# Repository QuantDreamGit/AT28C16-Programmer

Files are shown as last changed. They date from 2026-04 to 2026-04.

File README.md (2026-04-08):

# 🧠 8-bit EEPROM Programmer & Display Decoder

This project implements an EEPROM-based lookup table to convert an 8-bit value into decimal digits using a hardware-only decoding approach.

The EEPROM is programmed using an Arduino Nano Every and a shift-register-driven address bus.

## 📌 Overview

The system:

* Converts `0x00–0xFF` into decimal digits
* Supports both **unsigned** and **two’s complement signed** formats
* Uses EEPROM as a **hardware lookup table**
* Drives a segmented display via precomputed values

## ⚙️ Architecture

* **MCU**: Arduino Nano Every (20 MHz)
* **Shift Register**: 74HC164 (serial → parallel address)
* **EEPROM**: AT28Cxx family
* **Data bus**: 8-bit parallel
* **Control signals**: `WE`, `OE`, `CLR`

Addresses are shifted serially into the 74HC164, while data is written in parallel.

## 🧩 EEPROM Memory Map

### Unsigned (`0x00–0xFF`)

| Address | Content |
| --- | --- |
| `0x000–0x0FF` | Ones |
| `0x100–0x1FF` | Tens |
| `0x200–0x2FF` | Hundreds |
| `0x300–0x3FF` | Sign (`0x00`) |

### Signed (`-128 → 127`)

| Address | Content |
| --- | --- |
| `0x400–0x4FF` | Ones |
| `0x500–0x5FF` | Tens |
| `0x600–0x6FF` | Hundreds |
| `0x700–0x7FF` | Sign (`0x00` / `0x80`) |

* Digits use `abs(value)`
* Negative numbers use sign byte `0x80`

## 🔢 Segment Encoding

| Digit | Hex |
| ----- | --- |
| 0 | `0x7B` |
| 1 | `0x12` |
| 2 | `0xB9` |
| 3 | `0xB3` |
| 4 | `0xD2` |
| 5 | `0xE3` |
| 6 | `0xEB` |
| 7 | `0x32` |
| 8 | `0xFB` |
| 9 | `0xF2` |
| - | `0x80` |

## 🛠️ Programming Flow

For each byte:

1. Clear shift register
2. Shift 11-bit address (MSB → LSB)
3. Set data bus (`D0–D7`)
4. Pulse `WE` (write enable)
5. Wait for write cycle (~2 ms)

Readback uses the same address logic with `OE` enabled.

## ⚡ Timing Notes

* Arduino @ 20 MHz → ~50 ns per cycle
* `digitalWrite()` already satisfies all timing constraints
* EEPROM write cycle dominates (~1–2 ms)
* No latch in 74HC164 → register is cleared before each address load

## 🖼️ Assets

### Schematic

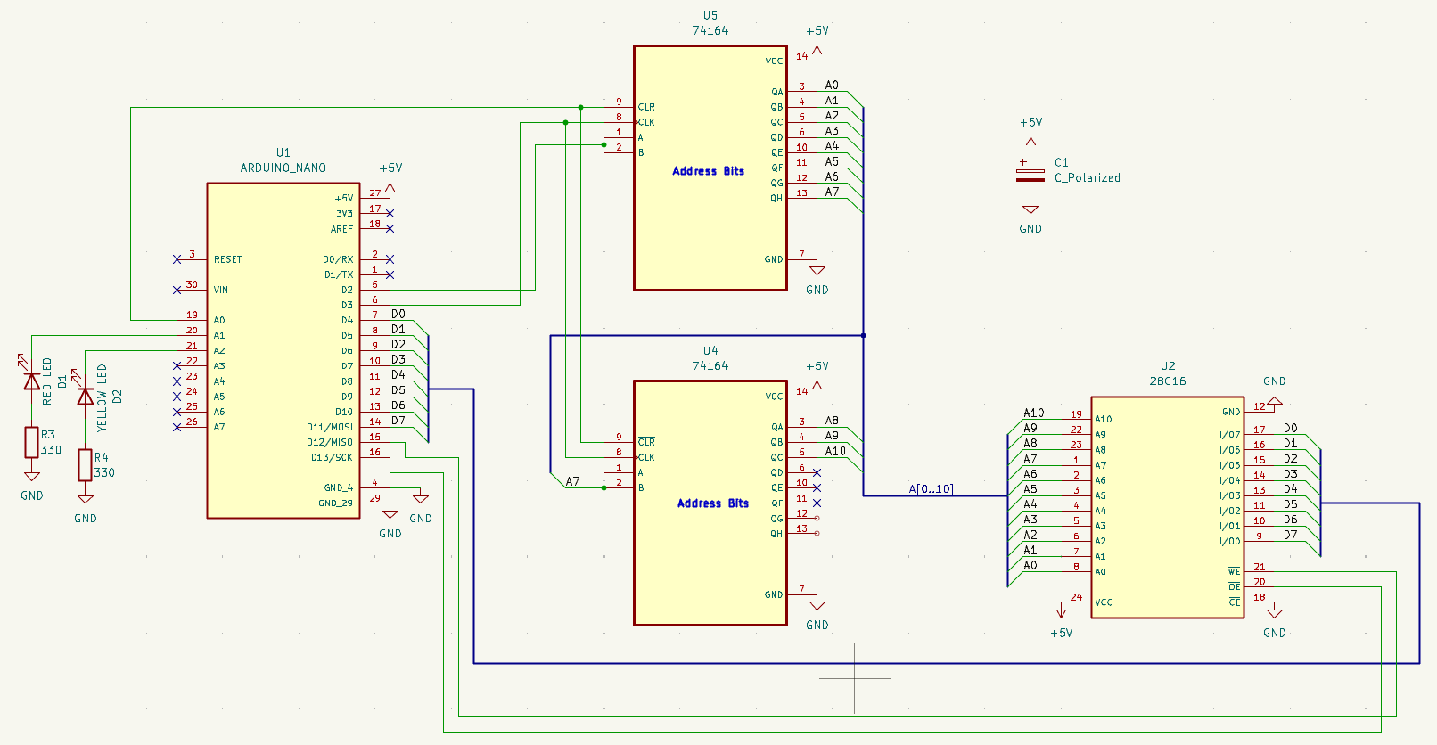
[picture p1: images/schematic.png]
Schematic


### PCB

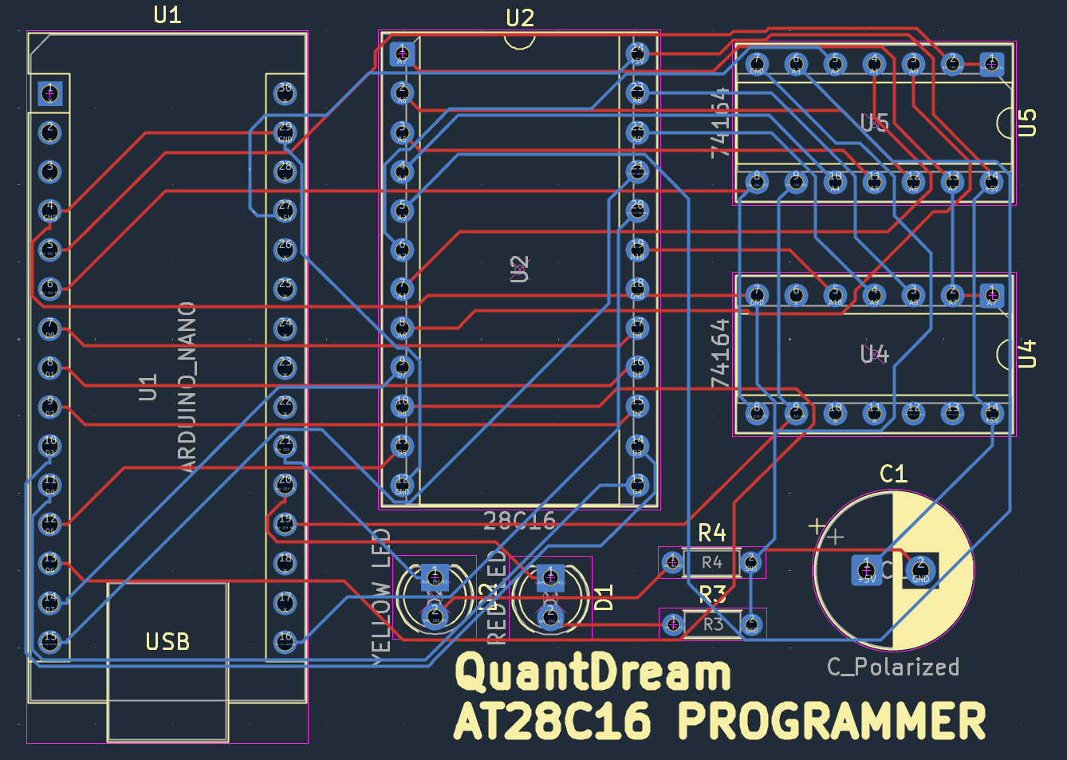
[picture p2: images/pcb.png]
PCB


### 3D View

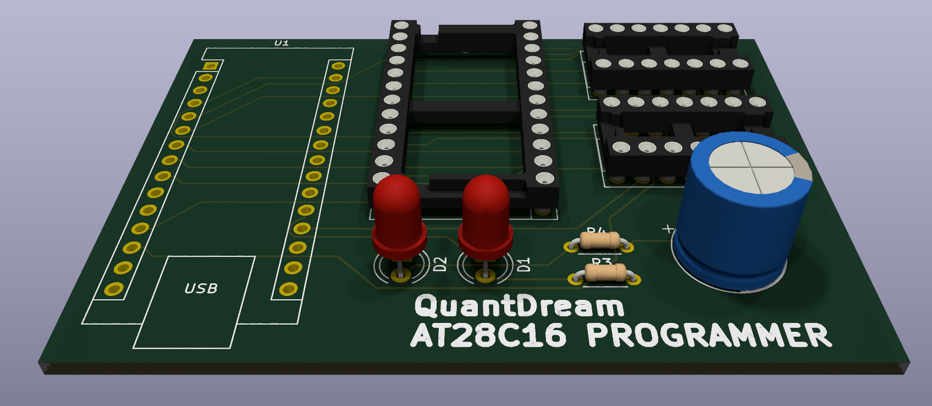
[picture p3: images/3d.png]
3D


### Gerbers

Gerbers

---

## 📁 Structure

```plaintext
.
├── firmware/
├── hardware/
├── images/
└── README.md
```

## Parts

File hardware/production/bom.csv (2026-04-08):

Designator | Footprint | Quantity | Value | LCSC Part #
C1 | CP_Radial_D10.0mm_P3.50mm | 1 | C_Polarized
D1 | LED_D4.0mm | 1 | RED LED
D2 | LED_D4.0mm | 1 | YELLOW LED
R3, R4 | R_Axial_DIN0204_L3.6mm_D1.6mm_P5.08mm_Horizontal | 2 | 330
U1 | Arduino_Nano | 1 | ARDUINO_NANO
U2 | DIP-24_W15.24mm_Socket | 1 | 28C16
U4, U5 | DIP-14_W7.62mm_Socket | 2 | 74164

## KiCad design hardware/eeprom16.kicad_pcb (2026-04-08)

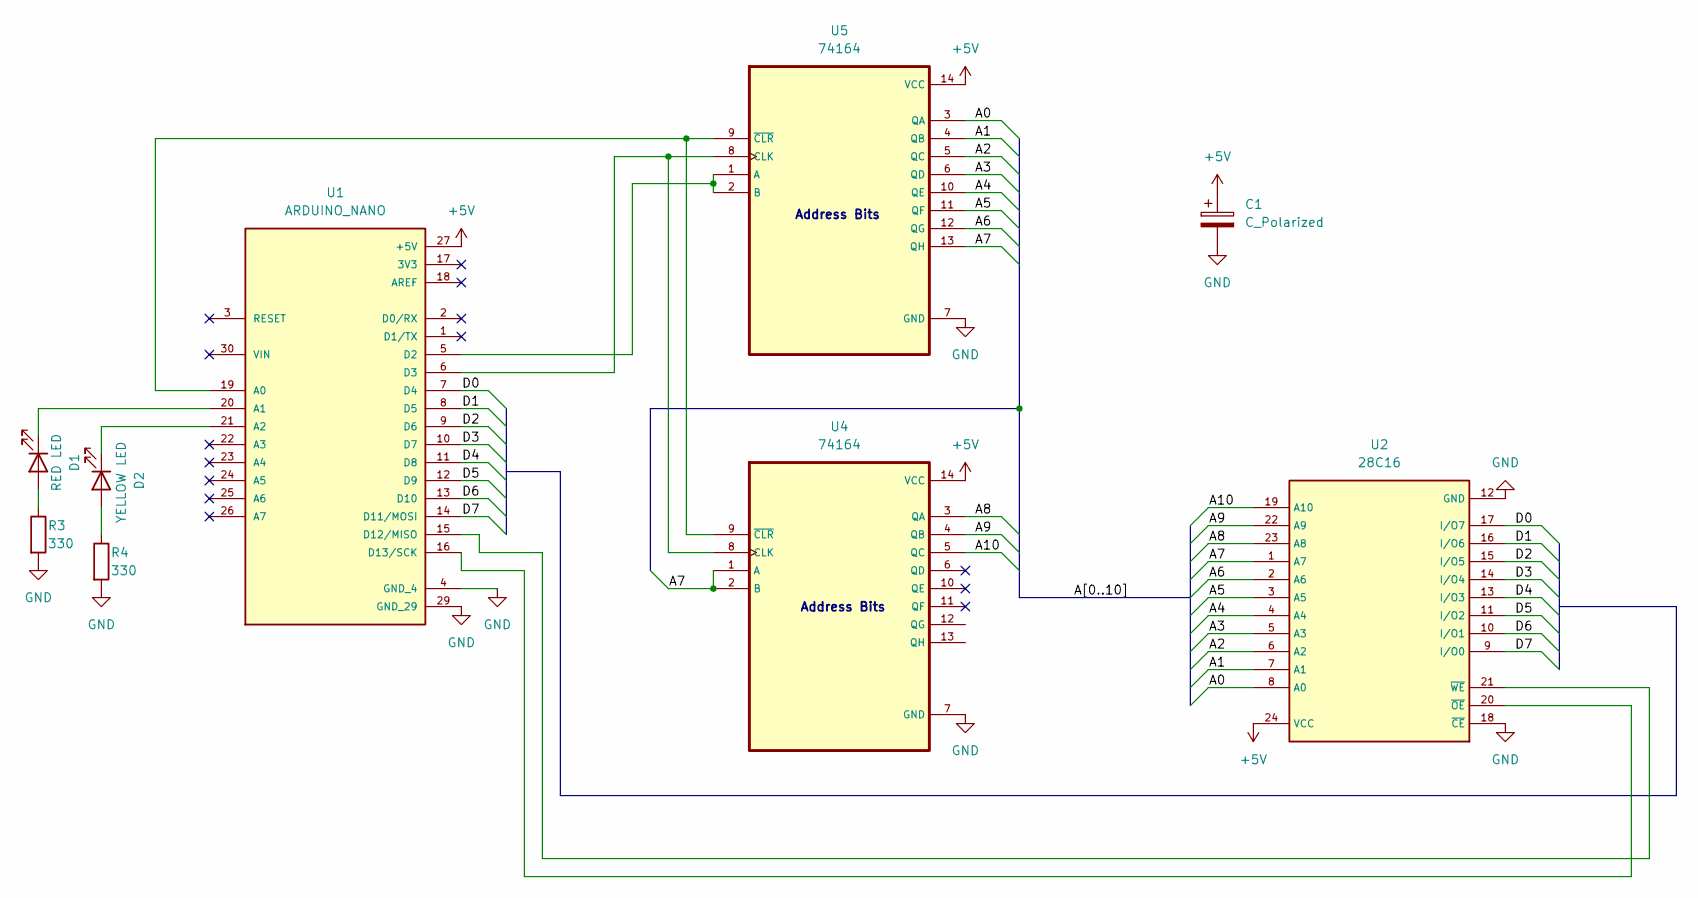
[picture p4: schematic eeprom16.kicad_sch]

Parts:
C1: C_Polarized; CP_Radial_D10.0mm_P3.50mm
D1: RED LED; LED_D4.0mm
D2: YELLOW LED; LED_D4.0mm
R3, R4: 330; R_Axial_DIN0204_L3.6mm_D1.6mm_P5.08mm_Horizontal
U1: ARDUINO_NANO; Arduino_Nano; PARTREV 30/06/2021
U2: 28C16; DIP-24_W15.24mm_Socket
U4, U5: 74164; DIP-14_W7.62mm_Socket

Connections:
+5V: C1.1, U1.27 (+5V), U2.24 (VCC), U4.14 (VCC), U5.14 (VCC)
/A0: U2.8 (A0), U5.3 (QA)
/A1: U2.7 (A1), U5.4 (QB)
/A2: U2.6 (A2), U5.5 (QC)
/A3: U2.5 (A3), U5.6 (QD)
/A4: U2.4 (A4), U5.10 (QE)
/A5: U2.3 (A5), U5.11 (QF)
/A6: U2.2 (A6), U5.12 (QG)
/A7: U2.1 (A7), U4.1 (A), U4.2 (B), U5.13 (QH)
/A8: U2.23 (A8), U4.3 (QA)
/A9: U2.22 (A9), U4.4 (QB)
/A10: U2.19 (A10), U4.5 (QC)
/D0: U1.7 (D4), U2.17 (I/O7)
/D1: U1.8 (D5), U2.16 (I/O6)
/D2: U1.9 (D6), U2.15 (I/O5)
/D3: U1.10 (D7), U2.14 (I/O4)
/D4: U1.11 (D8), U2.13 (I/O3)
/D5: U1.12 (D9), U2.11 (I/O2)
/D6: U1.13 (D10), U2.10 (I/O1)
/D7: U1.14 (D11/MOSI), U2.9 (I/O0)
GND: C1.2, R3.2, R4.2, U1.4 (GND_4), U1.29 (GND_29), U2.12 (GND), U2.18 (~CE), U4.7 (GND), U5.7 (GND)
unnamed: D1.2 (A), R3.1
unnamed: D1.1 (K), U1.20 (A1)
unnamed: D2.2 (A), R4.1
unnamed: D2.1 (K), U1.21 (A2)
unnamed: U1.19 (A0), U4.9 (~CLR), U5.9 (~CLR)
unnamed: U1.5 (D2), U5.1 (A), U5.2 (B)
unnamed: U1.6 (D3), U4.8 (CLK), U5.8 (CLK)
unnamed: U1.15 (D12/MISO), U2.21 (~WE)
unnamed: U1.16 (D13/SCK), U2.20 (~OE)

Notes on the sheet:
Address Bits

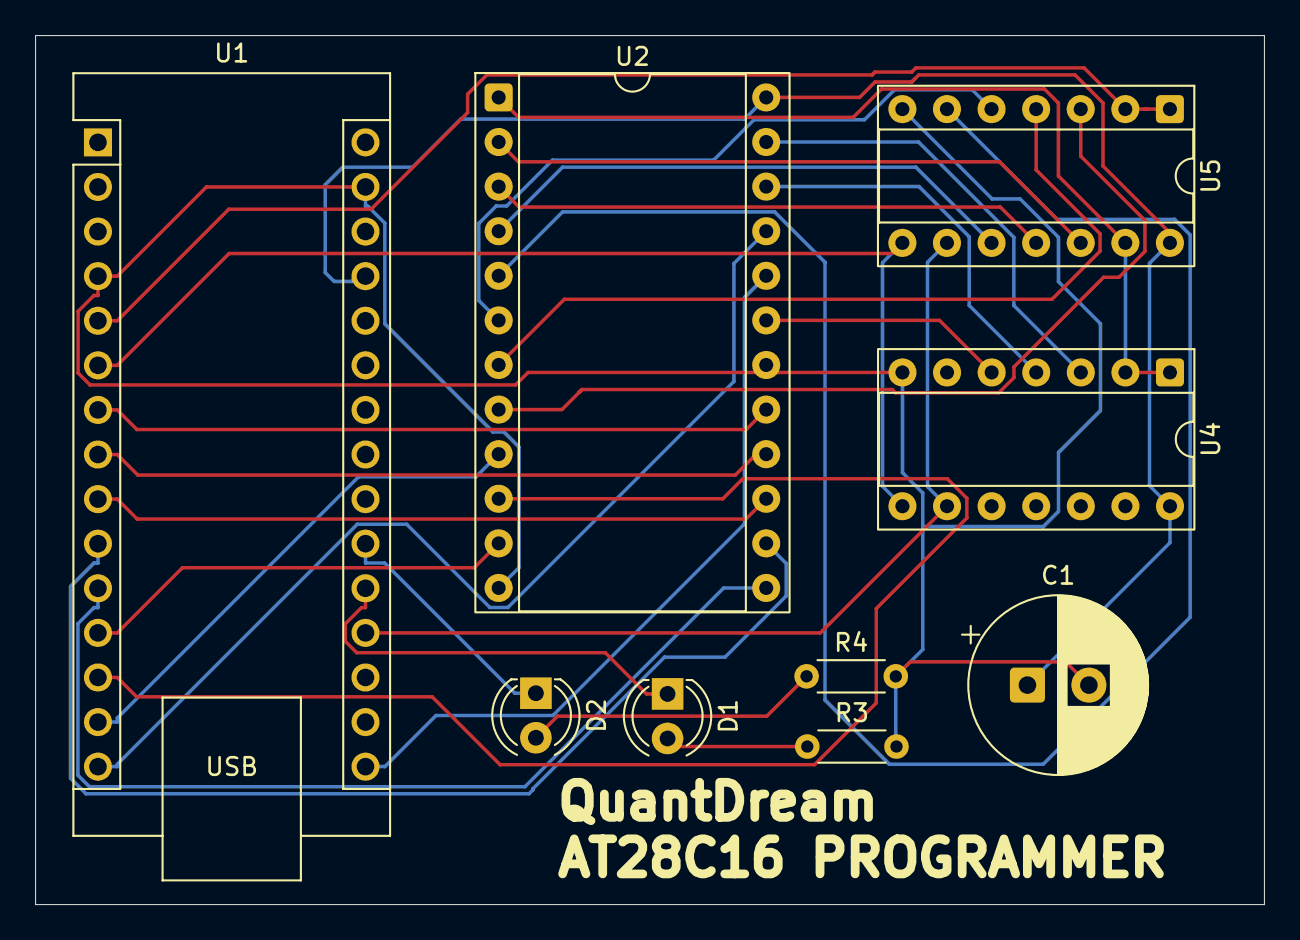
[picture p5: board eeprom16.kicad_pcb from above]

Board: 2 copper layers, 70.0 x 49.5 mm, 9 parts (0 on the bottom side), 30 nets.

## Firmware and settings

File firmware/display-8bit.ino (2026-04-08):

// For this project I use arudino nano every that can go up to 20MHz
// In this case each clock cycle should be around 50ns more than enough for all computations
// (considering that most oprations such as digitalWrite require well above 1 cycle!)
// So I'll comment delays but be careful with other boards!

// Data bus (D0–D7)
const int dataPins[8] = {4, 5, 6, 7, 8, 9, 10, 11};

// Shift register pins (74HC164)
const int dataPin = 2;
const int clockPin = 3;

// EEPROM control pins
const int oePin = 13;
const int wePin = 12;
const int clearPin = A0;

// --------------------------------------------------
// Shift address into the 74HC164
// --------------------------------------------------
void setAddress(unsigned int address) {
  for (int i = 10; i >= 0; i--) {
    // Minimum pulse width is 20ns
    // This way we are quite safe with 1us
    // Data is shifted on the rising edge of the clock pulse

    // Data cycle
    digitalWrite(clockPin, LOW);
    // delayMicroseconds(1);
    // Insert current 1/0
    digitalWrite(dataPin, (address >> i) & 1);
    // Shift data
    digitalWrite(clockPin, HIGH);
    // delayMicroseconds(1);
  }
}

void clearShiftRegister() {
  // Average time required is 50ns to clear
  digitalWrite(clearPin, LOW);
  // delayMicroseconds(1);
  digitalWrite(clearPin, HIGH);
}

// --------------------------------------------------
// Write one byte to EEPROM 
// --------------------------------------------------
void writeEEPROM(unsigned int address, byte data) {
  // Disable EEPROM
  digitalWrite(wePin, HIGH);
  digitalWrite(oePin, HIGH);

  // Clear shift register
  clearShiftRegister();

  // Set address
  setAddress(address);

  // Put data on bus
  for (int i = 0; i < 8; i++) {
    pinMode(dataPins[i], OUTPUT);
    digitalWrite(dataPins[i], (data >> i) & 1);
  }

  // Write pulse
  // Between 100-1000ns
  digitalWrite(wePin, LOW);
  // delayMicroseconds(1);
  digitalWrite(wePin, HIGH);

  // Wait for internal write cycle
  // Datasheet says max 1ms
  delay(2);
}

// --------------------------------------------------
// Read one byte from EEPROM 
// --------------------------------------------------
byte readEEPROM(unsigned int address) {
  digitalWrite(wePin, HIGH);
  digitalWrite(oePin, HIGH);

  // Clear shift register before loading new address
  clearShiftRegister();

  // Set address twice
  setAddress(address);

  // Data bus as input
  for (int i = 0; i < 8; i++) {
    pinMode(dataPins[i], INPUT);
  }

  // Enable EEPROM output
  // Should be around 10ns
  digitalWrite(oePin, LOW);
  // delayMicroseconds(1);

  byte data = 0;
  for (int i = 0; i < 8; i++) {
    data |= (digitalRead(dataPins[i]) << i);
  }

  digitalWrite(oePin, HIGH);

  return data;
}

// --------------------------------------------------
// Print full EEPROM contents
// --------------------------------------------------
void printContents() {
  for (unsigned int base = 0; base < 2048; base += 16) {
    byte data[16];

    for (int offset = 0; offset < 16; offset++) {
      data[offset] = readEEPROM(base + offset);
    }

    char buf[100];
    sprintf(buf,
            "%03x:  %02x %02x %02x %02x %02x %02x %02x %02x   %02x %02x %02x %02x %02x %02x %02x %02x",
            base,
            data[0], data[1], data[2], data[3],
            data[4], data[5], data[6], data[7],
            data[8], data[9], data[10], data[11],
            data[12], data[13], data[14], data[15]);

    Serial.println(buf);
  }
}

void setup() {
  Serial.begin(9600);

  pinMode(dataPin, OUTPUT);
  pinMode(clockPin, OUTPUT);
  pinMode(oePin, OUTPUT);
  pinMode(wePin, OUTPUT);
  pinMode(clearPin, OUTPUT);

  digitalWrite(wePin, HIGH);
  digitalWrite(oePin, HIGH);
  digitalWrite(clearPin, HIGH);

  delay(500);

  // Your digit patterns
  byte digits[] = {
    0x7B, // 0
    0x12, // 1
    0xB9, // 2
    0xB3, // 3
    0xD2, // 4
    0xE3, // 5
    0xEB, // 6
    0x32, // 7
    0xFB, // 8
    0xF2  // 9
  };

  const byte minusSign = 0x80;

  // Unsigned 0..255
  Serial.println("Programming ones place");
  for (int value = 0; value <= 255; value++) {
    writeEEPROM(value, digits[value % 10]);
  }

  Serial.println("Programming tens place");
  for (int value = 0; value <= 255; value++) {
    writeEEPROM(value + 256, digits[(value / 10) % 10]);
  }

  Serial.println("Programming hundreds place");
  for (int value = 0; value <= 255; value++) {
    writeEEPROM(value + 512, digits[(value / 100) % 10]);
  }

  Serial.println("Programming sign");
  for (int value = 0; value <= 255; value++) {
    writeEEPROM(value + 768, 0x00);
  }

  // Signed -128..127 (two's complement)
  Serial.println("Programming ones place (twos complement)");
  for (int value = -128; value <= 127; value++) {
    writeEEPROM((byte)value + 1024, digits[abs(value) % 10]);
  }

  Serial.println("Programming tens place (twos complement)");
  for (int value = -128; value <= 127; value++) {
    writeEEPROM((byte)value + 1280, digits[abs(value / 10) % 10]);
  }

  Serial.println("Programming hundreds place (twos complement)");
  for (int value = -128; value <= 127; value++) {
    writeEEPROM((byte)value + 1536, digits[abs(value / 100) % 10]);
  }

  Serial.println("Programming sign (twos complement)");
  for (int value = -128; value <= 127; value++) {
    if (value < 0) {
      writeEEPROM((byte)value + 1792, minusSign);
    } else {
      writeEEPROM((byte)value + 1792, 0x00);
    }
  }

  Serial.println("Reading EEPROM");
  printContents();
}

void loop() {
}
